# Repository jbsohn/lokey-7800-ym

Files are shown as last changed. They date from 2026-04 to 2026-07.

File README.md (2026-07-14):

# Lokey 7800 YM

> **Status:** v0.2 PCBs have been sent to the manufacturer — prototype boards are pending, and we're working on hardware validation.

## Project Overview

The Atari 7800 community's favorite audio upgrades have a supply problem: POKEY clones run **~$10-$40 each — when they're in stock** — and the YM2151 has been out of production for decades, commanding collector prices used. The **Lokey 7800 YM** takes a different route: the **YM2149 PSG** — the Atari ST's sound chip — is still manufactured today as the **KC89C72** clone for **about $2**. One in-production chip brings three-channel sound to the 7800, and with it a direct bridge to four decades of Atari ST music and a tracker ecosystem that is still alive and composing. Original YM2149 chips are also plentiful as used or New-Old-Stock (NOS) parts.

### What's in a Name?

The **Lokey** name is a triple-layered nod to the project's roots:

- **POKEY**: A respectful "cousin" to Atari’s legendary sound chip.
- **Low-Key**: Reflecting our philosophy of a minimalist, stealthy, and cost-effective design.
- **Loki**: Inspired by the Norse god of mischief—bringing a bit of technical "trickery" to the Atari 7800 bus.

The project views the **Atari ST** as a potential **Creation System**.
With established trackers (like Protracker ST or Maxymiser), it offers a path for audio production. Modern cross-platform tools like [**Furnace Tracker**](https://tildearrow.org/furnace) and [**Arkos Tracker**](https://www.julien-nevo.com/arkostracker/) (which is dedicated specifically to the AY/YM architecture) can also export VGM data for use with our tools on the 7800.

The **Atari 7800** acts as the **Consumer** of these assets. By bridging the hardware gap, we hope to allow the 7800 to play music from the ST era or new compositions from modern trackers.

### Design Goals

- **In-Production Parts Only**: No POKEY or YM2151 unobtainium, and no expensive FPGAs. Every part on the BOM should be sourceable new today (e.g. the KC89C72 YM2149 clone).
- **No SMD**: Hand-solderable through-hole components only, so hobbyists without a hot air rework station can build and repair boards.
- **Low Cost**: Keep the total build cost minimal.
- **Time-Period Accurate**: Stay faithful to what would have been technically feasible/authentic to the Atari 7800/ST era, rather than leaning on modern shortcuts.

### Hardware & Development Status

- **Working Prototype**: We have a hand-built cartridge prototype that has been verified to work.
- **PCB Effort**: We are working on a PCB design using a code-to-PCB workflow (**tscircuit**).
- **Reproducible Hardware Builds**: GitHub Actions rebuilds the PLD logic and both PCBs from source on every push. You can also build locally using the preconfigured **Docker Dev Container** (currently supported for building and routing PCBs).
- **Conversion Tools**: The project includes experimental tools to convert music files. The current C# implementation was a temporary hack to parse ST captures; this will be rewritten in C++ and optimized to support simultaneous music and sound effects playback.
- **SDK Progress**: We are working toward a set of tools and drivers to help others add YM music to their 7800 projects.
- **Custom Emulation**: For testing without hardware, we use forks of **a7800** and **js7800** that implement this specific memory mapping. _If this project gains momentum, we hope these changes might eventually be useful to the official upstream projects._

## Status: STABLE ALPHA

We have achieved playback on physical Atari 7800 consoles using a bitmask-compressed register engine. The current implementation is designed to be efficient, leaving significant CPU time for other tasks.

## See it in Action

### Hardware Prototype

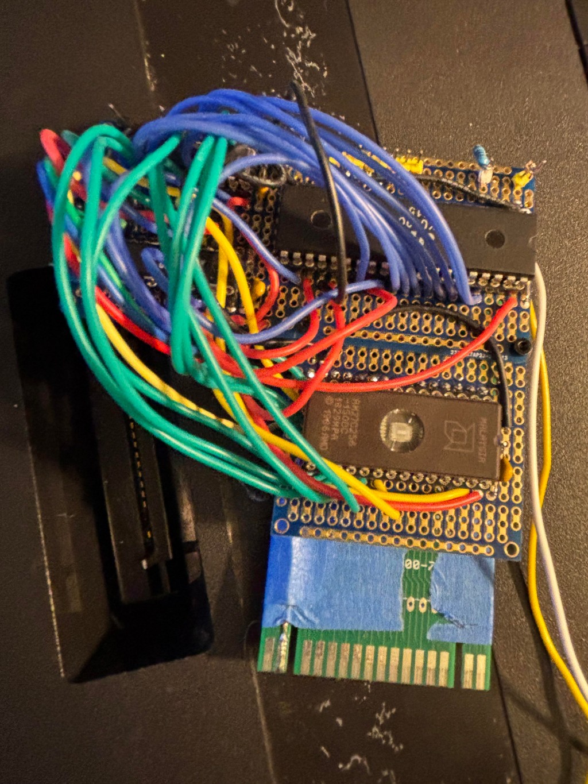
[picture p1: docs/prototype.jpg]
Atari 7800 YM2149 Cartridge Prototype


### Web Emulator (Instant Play)

Test the bridge right now in your browser using our custom **js7800** fork.
👉 **[Play the YM2149 Demos in your Browser](https://jbsohn.github.io/js7800-ym-player/)**

### Real Hardware (ANCOOL1 Stress Test)

This video shows a physical Atari 7800 playing a full 92-second capture of the "ANCOOL1" track, filling 96% of a single 32KB ROM bank to prove bus stability and engine efficiency.

ANCOOL1 Stress Test on Atari 7800 Hardware (https://www.youtube.com/shorts/LWzkfaaal2E)

## Documentation

- **[Development Guide](CLAUDE.md)** - Technical standards and build process for contributors and AI assistants.
- **[AI Development Agents](AGENTS.md)** - Specialized instructions for AI-assisted development and automation.
- **[SDK Samples & Building](docs/Samples.md)** - Compile ROMs and set up the environment.

- **[File Extension Reference](docs/FileExtensions.md)** - Guide to `.ymb`, `.ymi`, `.rom`, and `.a78` files.
- **[Hardware & Wiring](docs/Hardware.md)** - Shared memory mapping and connector/chip pinouts.
  - **[28-Pin Board](docs/Hardware-28pin.md)** - Single-YM2149, jumper-configured ROM board.
  - **[32-Pin Board](docs/Hardware-32pin.md)** - Bank-switched ROM board (fixed 32KB code + 16KB YM-IOA banked data window, 128KB-256KB) (Experimental Pre-Alpha v0.2 - Untested).

- **[PCB Design (tscircuit)](docs/PCB.md)** - Code-to-PCB workflow.

- **[Emulator Support](docs/Emulation.md)** - Using `a7800` and `js7800` for development.

- **[Toolchain & Diagnostics](docs/Tools.md)** - Register conversion (`YmToYmb`, `VgmToYmb`), audio verification (`YmbToWav`), and hardware signal verification.
- **[YMB Format](docs/YmbFormat.md)** - Technical specification of the music binary format.
- **[Musical Credits](docs/Musicians.md)** - Honoring the original composers.
- **[TODO](docs/TODO.md)** - Known issues and improvements.
- **[Future Ideas](docs/FutureIdeas.md)** - Roadmap for hardware/software expansions.

---

## Technical Highlights

- **Hardware**: Uses **YM2149 PSG** mapped to `$0800`/`$0801` (Pokey800-compatible).
- **Compression**: Multi-stage **Pattern-Based Delta Masking** for maximum ROM efficiency.
- **Timing**: Automatic **Pitch Scaling** (1.79MHz vs 2.0MHz) ensures tracks stay in tune.
- **Diagnostics**: Built-in **Software Triad** visualizer for bare-metal debugging.

## Acknowledgements & Credits

- **Karri Kaksonen (karrika)**: For the excellent [Otaku-flash](https://github.com/karrika/Otaku-flash) project. We have integrated the **Stable Alpha** Atari 7800 cartridge footprints, symbols, and professional design rules from this MIT-licensed repository.
- **Simon Frankau ([galette](https://github.com/simon-frankau/galette))**: For the open-source **galette** logic assembler. It provides a modern, cross-platform toolchain for compiling ATF16V8B/ATF22V10 logic, saving us from the legacy Windows tools.
- **Dan Boris (AtariHQ)**: For the indispensable [7800 Cartridge Technical Specifications](https://atarihq.com/danb/7800cart/a7800cart.shtml) and reference diagrams that made this hardware mapping possible.
- **Olivier PONCET (aym-js)**: For the excellent, high-fidelity [aym-js](https://github.com/ponceto/aym-js) YM2149/AY-3-8910 emulator core. Its tone/noise/envelope generator model and DAC tables underpin `tools/Core/AymEmulator.cs` (a literal C# port), which powers `YmbToWav`'s audio verification and has since been ported a second time into Go to give the `test7800` emulator fork native YM2149 support. A small, focused piece of GPL-licensed JavaScript that ended up doing a lot of work across this project — thank you!

- **Arnaud Carré (Leonard/OXG)**: For the excellent [StSound](https://github.com/arnaud-carre/StSound) project. The melodic assets used for hardware testing were sourced via this project's research.

- **Eagle & Ecernosoft**: For the insightful ideas and technical tips provided on the forums, including the Pokey800 mapping recommendation and the inspiration for the "Active Shunt" audio stage design.

- **Original Musicians & Composers**: For the timeless tracks used as benchmarks for this project. See **[Musical Credits](docs/Musicians.md)** for a full list of artists.

- **The Atari Community**: We are grateful to the dedicated fans keeping the 16-bit and 8-bit flames alive through archival and homebrew development.

## Contributing

This project is completely open source, and since this is a first-time PCB design, community feedback and contributions are highly welcome! _"Help! I need someone... not just anybody... you know I need someone!"_ as the Beatles said, so any help or review of the schematics, code, or board layout is greatly appreciated.

## AI Assistance

This project was developed with assistance from AI. For the author, AI has been a "force multiplier"—making it possible to tackle long-held "I've always wanted to do this" projects within the limited hours of evenings and weekends. In particular, it really helped with developing the [route_and_patch.py](file:///home/john/Projects/7800-ym2149-lab/pcb/route_and_patch.py) build pipeline.

For reflections on the legacy of the Atari ST and how AI is changing the landscape of hardware and software side-projects, see the author's blog posts:

[John's Music & Tech](https://johnsmusicandtech.com/)

## License

This repository is dual-licensed:

- **MIT License**: Applies to the 6502 target code ([examples/](file:///home/john/Projects/7800-ym2149-lab/examples) and [include/](file:///home/john/Projects/7800-ym2149-lab/include)). You can use, modify, and distribute this code in your homebrew games without any requirement to open-source your game. See [examples/LICENSE](file:///home/john/Projects/7800-ym2149-lab/examples/LICENSE) and [include/LICENSE](file:///home/john/Projects/7800-ym2149-lab/include/LICENSE).
- **GPL-2.0**: Applies to the host tools ([tools/](file:///home/john/Projects/7800-ym2149-lab/tools)), hardware layouts ([pcb/](file:///home/john/Projects/7800-ym2149-lab/pcb)), PLD logic ([pld/](file:///home/john/Projects/7800-ym2149-lab/pld)), and documentation. Modifying and redistributing these requires sharing your changes. Using these tools to build your ROM does not make your game GPL. See [LICENSE](file:///home/john/Projects/7800-ym2149-lab/LICENSE).

### Why the split?
The emulation core ([AymEmulator.cs](file:///home/john/Projects/7800-ym2149-lab/tools/Core/AymEmulator.cs)) is a C# port of Olivier Poncet's GPL-licensed **aym-js**, requiring GPL compatibility. Since the 6502 code shipped on the cartridge does not link or interact with the host emulator code, it remains under the permissive MIT license.

**Disclaimer:** Use at your own risk. The author is not responsible for hardware damage or data loss.

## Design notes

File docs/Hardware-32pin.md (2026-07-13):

# 32-Pin Board — Theory of Operation & Assembly Guide

**Experimental Pre-Alpha (v0.2):** The fixed+banked YM-IOA bank selection design has not been tested on physical hardware yet and is considered experimental pre-alpha. Use at your own risk. 

**Status:** v0.2 has been sent to the manufacturer; a prototype PCB is pending and this design is not yet hardware-verified.

This document covers the **32-pin ROM board** (`pcb/32pin.circuit.tsx`): a single-YM2149, bank-switched EPROM design with a native DIP-32 socket. The memory layout is SuperGame-style: a **fixed 32KB code bank at $8000–$FFFF** and a **switched 16KB data window at $4000–$7FFF**, with the bank number held in the YM2149's IOA port and decoded by the ATF22V10 PLD. For the shared memory map and pinout references common to all board variants, see [Hardware.md](Hardware.md). For the smaller, jumper-configured board, see [Hardware-28pin.md](Hardware-28pin.md).

## BOM Cost Estimation (Per Unit)

| Component | Part | Estimated Cost | Notes |
| :--- | :--- | :--- | :--- |
| **YM2149 / AY-3-8910 Clone** | U_YM | $2.00 | PSG (KC89C72) |
| **ATF22V10 (Logic)** | U_GAL | ~$1.50 | 24-pin PLD: address decode + bank mapping |
| **AT27C010/020/040 (EPROM)** | U_ROM | $2.00 | 128KB / 256KB (512KB part usable, top half only); native DIP-32 socket |
| **74HCT373 (Octal Latch)** | U_LATCH | $0.40 | Data bus isolation |
| **LM358 (Op-Amp)** | U_AMP | $0.10 | Summing amp for audio out |
| **Passives (R/C)** | — | $0.30 | Reset network, audio mixing, decoupling, 4× bank pull-ups |
| **Total (Excl. PCB)** | | **~$6.30** | |

## Logic Compilation (ATF22V10)

Unlike the 28-pin board (ATF16V8B), this board uses an **ATF22V10** (24-pin PLD). It performs both address decoding _and_ ROM bank mapping: the YM2149's IOA0–IOA3 pins feed the PLD, which generates the ROM's upper address lines A14–A17. Every pin of the PLD is used.

This project uses [**galette**](https://github.com/simon-frankau/galette), an open-source logic assembler. To compile into JEDEC files:

```bash
make logic
```

The source is `pld/rom_ym_32pin.pld`. Core equations:

```
/ROMCE  = A15 * RW  +  /A15 * A14 * RW     ; ROM window $4000–$FFFF, reads only
ROMA14  = A15 * A14 +  /A15 * IOA0         ; fixed: console A14; banked: bank bit 0
ROMA15  = A15 + IOA1                       ; fixed region forces the top of the chip
ROMA16  = A15 + IOA2
ROMA17  = A15 + IOA3
```

Because the fixed bank lives at the **top** of the EPROM (all upper address bits high), "force top bank" is a simple OR against A15 — no mux terms needed.

## Hardware Wiring

### 1. ATF22V10 Pinout (`U_GAL`)

| Pin | Signal | Source / Destination |
| :-- | :--- | :--- |
| 1 | PHI2 | 7800 CPU Clock (Cart Pin 32) |
| 2 | A15 | 7800 Address Bus |
| 3 | A14 | 7800 Address Bus |
| 4 | A13 | 7800 Address Bus |
| 5 | A12 | 7800 Address Bus |
| 6 | A11 | 7800 Address Bus |
| 7 | A0 | 7800 Address Bus |
| 8 | R/W | 7800 CPU R/W Line |
| 9 | HALT | 7800 Maria Halt Signal |
| 10  | IOA0 | ← U_YM Pin 21 (bank bit 0) |
| 11  | IOA1 | ← U_YM Pin 20 (bank bit 1) |
| 12  | GND | Ground |
| 13  | IOA2 | ← U_YM Pin 19 (bank bit 2) |
| 14  | IOA3 | ← U_YM Pin 18 (bank bit 3, used as input) |
| 15  | **ROM_A14** | → U_ROM Pin 29 (A14) |
| 16  | **ROM_A15** | → U_ROM Pin 3 (A15) |
| 17  | **ROM_A16** | → U_ROM Pin 2 (A16) |
| 18  | **ROM_A17** | → U_ROM Pin 30 (A17) |
| 19  | **!ROM_CE** | → U_ROM Pin 22 (~CE) |
| 20  | **BC1** | → U_YM Pin 29 |
| 21  | **BDIR** | → U_YM Pin 27 |
| 22  | **PHI2OUT** | Buffered Clock → U_YM Pin 22 |
| 23  | **YM_LE** | Latch Enable → 74HCT373 Pin 11 |
| 24  | VCC | +5V |

### 2. 74HCT373 Octal Latch Connections

| Latch Pin | Signal | Connection |
| :--- | :----- | :--- |
| 1 | ~OE | Ground |
| 2–9 | Q0–Q7  | U_YM DA0–DA7 |
| 3–18 | D0–D7  | 7800 Data Bus D0–D7 |
| 11 | LE | PLD Pin 15 (YM_LE)  |
| 20 | VCC | +5V |
| 10 | GND | Ground |

### 3. AT27C010/020/040 ROM (Native DIP-32 Socket)

The board carries a native 32-pin DIP-32 (600mil) socket compatible with the AT27C010 (128KB), AT27C020 (256KB), and AT27C040 (512KB) EPROM family. All three share the same pinout; only pins 30–31 differ in function across devices. The upper address lines **A14–A17 come from the PLD** (which muxes between console A14 and the YM IOA bank bits); only A0–A13 come directly from the console bus.

#### AT27C010 Pinout

| Pin (Left) | Signal | Pin (Right) | Signal |
| :--- | :--- | :--- | :--- |
| **1** | VPP (tied VCC) | **32** | VCC (+5V) |
| **2** | A16 ← PLD Pin 17 | **31** | A18/PGM (tied VCC) |
| **3** | A15 ← PLD Pin 16 | **30** | A17 ← PLD Pin 18 |
| **4** | A12 | **29** | A14 ← PLD Pin 15 |
| **5** | A7 | **28** | A13 |
| **6** | A6 | **27** | A8 |
| **7** | A5 | **26** | A9 |
| **8** | A4 | **25** | A11 |
| **9** | A3 | **24** | OE (tied GND) |
| **10** | A2 | **23** | A10 |
| **11** | A1 | **22** | ~CE ← PLD Pin 19 |
| **12** | A0 | **21** | D7 |
| **13** | D0 | **20** | D6 |
| **14** | D1 | **19** | D5 |
| **15** | D2 | **18** | D4 |
| **16** | GND | **17** | D3 |

> **Pin 30 (A17):** address input on AT27C020/040; no-connect on AT27C010.
> **Pin 31 (A18/PGM):** on AT27C010/020 this is PGM (program enable, must be high for read) — tied to VCC. On AT27C040 it is A18, so tying it to VCC means the 512KB part exposes only its **top 256KB**; program images into the upper half.

### 4. YM2149 / AY-3-8910 Connections (U_YM)

#### Bus & Control

| YM Pin | Signal  | Connection |
| :----- | :--- | :--- |
| 22 | CLOCK | PHI2OUT (PLD Pin 22) |
| 27 | BDIR | PLD Pin 21 |
| 29 | BC1 | PLD Pin 20 |
| 28 | BC2 | VCC |
| 25 | A8 | VCC |
| 24 | !A9 | GND |
| 23 | !RESET  | RESET_DELAYED (RC network) |
| 30–37  | DA7–DA0 | 74HCT373 Q7–Q0 |

#### IOA Port — Bank Register

The YM's IOA port holds the current bank number. Software writes YM **register 14** (Port A); register 7 must configure IOA as output before use. The four bank lines feed the **PLD** (not the ROM directly), each with a **10kΩ pull-up** (`R_BANK0–3`) to VCC.

| YM Pin | Signal | Function |
| :----- | :--- | :--- |
| 21 | IOA0 | Bank bit 0 → U_GAL Pin 10 |
| 20 | IOA1 | Bank bit 1 → U_GAL Pin 11 |
| 19 | IOA2 | Bank bit 2 → U_GAL Pin 13 |
| 18 | IOA3 | Bank bit 3 → U_GAL Pin 14 |
| 17–14  | IOA4–IOA7 | Unassigned |

### 5. Fixed + Banked Memory Layout

> [!NOTE]
> This bank switching scheme is currently experimental pre-alpha and has not yet been tested on physical hardware.

SuperGame-style split, decoded entirely in the ATF22V10:

| Console address | Contents | ROM location |
| :--- | :--- | :--- |
| $8000–$FFFF | **Fixed 32KB** — player code, header, vectors | Top 32KB of the chip (always mapped, ignores IOA) |
| $4000–$7FFF | **Switched 16KB window** — song/level data | 16KB bank _N_, where _N_ = IOA[3:0] |

Software protocol (unchanged from v0.2):

```
Write YM reg 7  (Mixer/IO):  bit 6 = 1 (IOA = output) — preserve mixer bits 0-5!
Write YM reg 14 (Port A):    bits[3:0] = bank number (16KB units)
```

> **Register 7 discipline:** bit 6 of register 7 shares the register with the tone/noise mixer. Every mixer write in the player must OR in `$40` or the bank register reverts to input mode (floating → pull-ups → top bank). With the fixed code bank this is no longer fatal — it only redirects the **data window** — but it will still corrupt whatever the player is streaming.

Supported configurations (16KB banks; the top two banks are the fixed 32KB region, visible in the data window only as mirrors):

| ROM part | Capacity | Data banks |
| :--- | :--- | :--- |
| AT27C010 | 128KB | 6 × 16KB (banks 0–5; IOA3 ignored) |
| AT27C020 | 256KB | 14 × 16KB (banks 0–13) |
| AT27C040 | 512KB (top half used) | 14 × 16KB (banks 0–13) |

> [!IMPORTANT]
> **Known limitation of this revision:** 14 usable banks (256KB) is a hard limit, not a soft one — to be addressed in a later revision.

**Power-on behaviour:** at reset the YM's IOA port is in input mode (Hi-Z), so the pull-ups select bank 15 and the data window shows a mirror of $C000–$FFFF — harmless. The reset vectors and boot code live in the **fixed** bank, which is always mapped, so **no code or vector duplication across banks is required**. Bank switching only ever moves the $4000–$7FFF data window.

### 6. Hardware Reset Logic (Warm Start Fix)

An RC network on YM **Pin 23 (!RESET)** prevents the warm-start stuck-tone issue caused by a quick power cycle bypassing BIOS delays.

1. **10kΩ pull-up:** VCC → Pin 23 (!RESET)
2. **10µF polarised cap:** (+) to Pin 23 (!RESET), (−) to GND

At power-up the discharged cap holds !RESET low for ~100ms while the +5V rail stabilises, then releases it high.

### 7. LM358 Audio Stage (U_AMP — Inverting Summing Amp)

YM channels A, B, C each pass through a **1kΩ isolation resistor** to a shared **SUM_NODE**.

| Pin | Signal  | Connection |
| :---- | :--- | :--- |
| **1** | OUT1 | Op-amp output → R_FB → SUM_NODE (feedback) |
| **2** | IN1_NEG | SUM_NODE |
| **3** | IN1_POS | GND |
| **4** | GND | Ground Plane |
| **5** | IN2_POS | GND (unused channel stability) |
| **6** | IN2_NEG | OUT2 (unity-gain follower) |
| **7** | OUT2 | IN2_NEG (unity-gain follower) |
| **8** | VCC | +5V |

**Output path:** OUT1 → R_SERIES (1kΩ) → C_AUDIO_OUT (+) (10µF) → C_AUDIO_OUT (−) → **Exaudio (Cart Pin 18)**. The R_PULL (1kΩ) from OUT1 to GND biases the output stage into Class-A operation.

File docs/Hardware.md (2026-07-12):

# Hardware Specification & Wiring

This document contains the technical hardware specifications, memory mapping, and pinout references shared across all board variants of the YM2149 Atari 7800 bridge.

## Board Variants

This project has two board designs, each with its own dedicated hardware doc for PLD/ROM wiring, jumpers, and BOM:

* **[28-Pin Board](Hardware-28pin.md)** (`pcb/28pin.circuit.tsx`) — single YM2149, ATF16V8B PLD, solder-jumper ROM size selection (16/32/64KB).
* **[32-Pin Board](Hardware-32pin.md)** (`pcb/32pin.circuit.tsx`) — single YM2149, ATF22V10 PLD, native DIP-32 socket. Fixed 32KB code bank at $8000–$FFFF plus a switched 16KB data window at $4000–$7FFF, bank-selected via the YM IOA port through the PLD (128KB–256KB usable).

Everything below this section — the memory map and connector/chip pinout references — applies to both boards.

## Memory Mapping

The YM2149 is mapped to two specific addresses:

| Address | Function |
| :--- | :--- |
| **$0800** | YM2149 Address Register (select internal register) |
| **$0801** | YM2149 Data Register (write value to selected register) |

This mapping follows the **"YM $800" / Pokey800-compatible** decoding scheme: the PLD decodes a single address bit (`A11`, with `A15-A12` all low) rather than mirroring the chip across a wide window. This frees the entire `$4000-$7FFF` cartridge ROM window for actual game data instead of write-only sound registers, at the cost of dropping compatibility with the older "classic POKEY@$4000" mapping used by games like **Ballblazer** and **Commando**.

### Write-Only Mirroring

The current logic implementation is gated by the `!RW` (Read/Write) line. This means the YM2149 is a "write-only" device at $0800. This allows other devices (like ROM or RAM) to reside at the same memory addresses for **read** operations without bus contention.

---

## Hardware Pinout Reference

### 7800 Cartridge Edge (32-Pin)

From [AtariHQ](https://atarihq.com/danb/7800cart/a7800cart.shtml):

| Pin (1–16) | Signal | Pin (32–17) | Signal |
| :--- | :--- | :--- | :--- |
| **1** | Read/Write (low=Write) | **32** | Phase 2 Clock |
| **2** | Halt | **31** | IRQ |
| **3** | D3 | **30** | Ground |
| **4** | D4 | **29** | D2 |
| **5** | D5 | **28** | D1 |
| **6** | D6 | **27** | D0 |
| **7** | D7 | **26** | A0 |
| **8** | A12 | **25** | A1 |
| **9** | A10 | **24** | A2 |
| **10** | A11 | **23** | A3 |
| **11** | A9 | **22** | A4 |
| **12** | A8 | **21** | A5 |
| **13** | +5V VDC | **20** | A6 |
| **14** | Ground | **19** | A7 |
| **15** | A13 | **18** | External Audio Input |
| **16** | A14 | **17** | A15 |

### AY-3-8910 / YM2149 PSG (40-Pin)

| Pin (Left) | Signal | Pin (Right) | Signal |
| :--- | :--- | :--- | :--- |
| **1** | VSS (Ground) | **40** | VCC (+5V) |
| **2** | N.C. | **39** | TEST 1 |
| **3** | Analog Channel B | **38** | Analog Channel C |
| **4** | Analog Channel A | **37** | DA0 |
| **5** | N.C. | **36** | DA1 |
| **6** | IOB7 | **35** | DA2 |
| **7** | IOB6 | **34** | DA3 |
| **8** | IOB5 | **33** | DA4 |
| **9** | IOB4 | **32** | DA5 |
| **10** | IOB3 | **31** | DA6 |
| **11** | IOB2 | **30** | DA7 |
| **12** | IOB1 | **29** | BC1 |
| **13** | IOB0 | **28** | BC2 (Tie High) |
| **14** | IOA7 | **27** | BDIR |
| **15** | IOA6 | **26** | N.C. |
| **16** | IOA5 | **25** | A8 (Tie High) |
| **17** | IOA4 | **24** | !A9 (Tie Low) |
| **18** | IOA3 | **23** | !RESET |
| **19** | IOA2 | **22** | CLOCK |
| **20** | IOA1 | **21** | IOA0 |

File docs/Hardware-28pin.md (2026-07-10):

# 28-Pin Board — Theory of Operation & Assembly Guide

This document covers the **28-pin ROM board** (`pcb/28pin.circuit.tsx`, formerly "Rev 1"): a single-YM2149, jumper-configurable-ROM-size cartridge. For the shared memory map and pinout references common to all board variants, see [Hardware.md](Hardware.md). For the larger dual-YM/bank-switching board, see [Hardware-32pin.md](Hardware-32pin.md).

## BOM Cost Estimation (Per Unit)

The 28-pin board is designed for high performance at a hobbyist-friendly price point.

| Component | Estimated Cost | Notes |
| :--- | :--- | :--- |
| **YM2149 / AY-3-8910 Clone** | $2.00 | Targeted price for bulk/clones |
| **ATF16V8B (PLD)** | $0.85 | Modern replacement for legacy GAL16V8 |
| **27C256 (32KB EPROM)** | $1.50 | Standard game ROM (16KB/64KB parts also supported, see jumper table below) |
| **74HCT373 (Octal Latch)** | $0.40 | Address latching |
| **LM358 (Op-Amp)** | $0.10 | Active audio amplification |
| **Passives (R/C)** | $0.15 | Reset circuit and audio stage |
| **Total (Excl. PCB)** | **~$5.00** | |

## Logic Compilation (ATF16V8B)

The cartridge uses a programmable logic device (typically an **ATF16V8B** or legacy **GAL16V8**) to handle the address decoding and bus control logic.

This project uses [**galette**](https://github.com/simon-frankau/galette), an open-source logic assembler, for a modern, cross-platform toolchain.

To compile the logic into JEDEC files (for use with a device programmer):
```bash
make logic
```

---

## 1. System Architecture

The 28-pin board bridges the Atari 7800 console's expansion bus with a YM2149 Sound Generator (PSG) and a game EPROM (up to 64KB, jumper-selectable).

```mermaid
graph TD
    subgraph Atari 7800 Console
        Bus[Address & Data Bus]
        Phi2[PHI2 Clock]
        Halt[HALT Pin]
        RW[R/W Pin]
        Exaudio[Exaudio Input Pin 18]
    end

    subgraph 28-Pin Cartridge
        GAL[ATF16V8B PLD]
        Latch[74HCT373 Latch]
        YM[YM2149 PSG]
        ROM[27C256/27C512-family ROM]
        Mixer[LM358 Audio Stage]
        JP1[JP1 Jumper]
        JP2[JP2 Jumper]
    end

    Bus -->|A15-A11, A0, R/W, PHI2, HALT| GAL
    Bus -->|D0-D7| Latch
    Bus -->|D0-D7| ROM
    Bus -->|A0-A13| ROM

    GAL -->|ROM_CE| ROM
    GAL -->|YM_LE| Latch
    GAL -->|BDIR, BC1, PHI2OUT| YM

    Latch -->|DA0-DA7| YM
    JP1 -->|Pin 1 VPP/A15| ROM
    JP2 -->|Pin 27 A14| ROM

    YM -->|Analog A, B, C| Mixer
    Mixer -->|AC Out| Exaudio
```

---

## 2. Address Decoding & Memory Map

The PLD (`U_GAL` — ATF16V8B) acts as the address decoder (see [Hardware.md](Hardware.md#memory-mapping) for the full $0800/$0801 register mapping shared across boards):

* **ROM reads ($4000–$FFFF)**:
  * When `RW = 1` (read) and (`A15 = 1` or `A14 = 1`), the PLD asserts `/ROM_CE` (Pin 19) `LOW`, enabling the EPROM (`U_ROM`).
  * The ROM drives the data bus (`D0–D7`) to return game instructions. This covers both the $8000–$FFFF (32KB, `A15=1`) and $4000–$7FFF (16KB, `A14=1`) windows — see the jumper table in [§7](#7-solder-jumper-configurations-rom-size) for how much of this is actually usable per ROM size.
* **Sound Card Register Space ($0800–$0801, writes only)**:
  * The PLD asserts YM2149 control signals when `A15 = A14 = A13 = A12 = 0` and `A11 = 1` during write cycles (`R/W = 0`). Since `RW = 0` here, `/ROM_CE` is not asserted, so there's no bus contention between the write-only YM2149 and the ROM's read path. Unlike the old $4000-mirrored scheme, this doesn't overlap the ROM window at all, so the full $4000–$FFFF range is available for actual game data.

### ATF16V8B Pinout (`U_GAL`)

Logic source: `pld/rom_ym_28pin.pld`.

| Pin | Signal | Source / Destination |
| :--- | :--- | :--- |
| 1 | CLK | Unused |
| 2 | A15 | 7800 Address Bus |
| 3 | A14 | 7800 Address Bus |
| 4 | A0 | 7800 Address Bus |
| 5 | HALT | 7800 Maria Halt Signal |
| 6 | R/W | 7800 CPU R/W Line |
| 7 | PHI2 | 7800 CPU Clock (Cart Pin 32) |
| 8 | A13 | 7800 Address Bus |
| 9 | A12 | 7800 Address Bus |
| 11 | A11 | 7800 Address Bus |
| 15 | **YM_LE** | Latch Enable → 74HCT373 Pin 11 |
| 16 | **PHI2OUT** | Buffered Clock → U_YM Pin 22 |
| 17 | **BC1** | → U_YM Pin 29 |
| 18 | **BDIR** | → U_YM Pin 27 |
| 19 | **!ROM_CE** | → U_ROM Pin 22/20 (~CE, ROM-size dependent) |
| 20 | VCC | +5V |

---

## 3. Data & Address Multiplexing (74HCT373)

The YM2149 uses a multiplexed address/data bus (`DA0–DA7`), while the Atari 7800 separates them.

* The **74HCT373 Octal Latch (`U_LATCH`)** bridges this gap:
  * When the CPU writes to the sound registers, the PLD asserts `YM_LE` (Latch Enable) `HIGH`.
  * This stores the current data bus value (`D0–D7`) in the latch.
  * The latch outputs (`Q0–Q7`) drive the YM2149's multiplexed pins (`DA0–DA7`), holding the address or data stable for the PSG.

| Latch Pin | Signal | Connection |
| :--- | :--- | :--- |
| 1 | ~OE | Ground |
| 2–9 | Q0–Q7 | U_YM DA0–DA7 |
| 3–18 | D0–D7 | 7800 Data Bus D0–D7 |
| 11 | LE | PLD Pin 15 (`YM_LE`) |
| 20 | VCC | +5V |
| 10 | GND | Ground |

---

## 4. YM2149 / AY-3-8910 Connections (U_YM)

| YM Pin | Signal | Connection |
| :--- | :--- | :--- |
| 22 | CLOCK | PHI2OUT (PLD Pin 16) |
| 27 | BDIR | PLD Pin 18 |
| 29 | BC1 | PLD Pin 17 |
| 28 | BC2 | VCC |
| 25 | A8 | VCC |
| 24 | !A9 | GND |
| 23 | !RESET | RESET_DELAYED (RC network, see [§5](#5-hardware-reset--warm-start-fix)) |
| 30–37 | DA7–DA0 | 74HCT373 Q7–Q0 |

---

## 5. Hardware Reset & Warm Start Fix

A common issue with retro PSG cartridges is a high-frequency stuck hum on system reset or quick power-cycle ("Warm Start"), caused by a quick power cycle bypassing the console's default internal BIOS delays and leaving the YM2149 registers holding garbage data. The **RC Reset Delay network (`R_RESET` / `C_RESET`)** on YM **Pin 23 (!RESET)** solves this.

### Connection & Wiring Guide

The two components meet at a single node connected directly to Pin 23 (!RESET) of the YM2149:

1. **Pull-up resistor (10kΩ):** VCC → Pin 23 (!RESET).
2. **Capacitor (10µF, polarized):** positive (+) terminal → Pin 23 (!RESET), negative (−) terminal → GND.

> **Note:** No manual reset switch is fitted on the PCB. The RC network provides automatic power-on reset only. For a manual override on a breadboard build, wire a normally-open switch in parallel with the capacitor (one contact to `!RESET`, the other to GND) — not required for normal cartridge operation.

### Theory of Operation

At power-up, the discharged capacitor acts as a momentary short to ground, holding `!RESET` low while the +5V rail stabilizes. The capacitor charges through the 10kΩ resistor over roughly 100ms, then releases `!RESET` high and allows the PSG to begin normal operation. This delay ensures the console BIOS has had time to silence the audio channels before the YM2149 comes out of reset, preventing the warm-start stuck-tone issue.

---

## 6. Audio Stage (LM358 — Active-Passive Hybrid Shunt Mixer)

The audio stage uses an LM358 op-amp (`U_AMP`) in a parallel **Active-Passive Hybrid Shunt** configuration. This design uses the op-amp's feedback loop and single-supply saturation limits to act as a passive load that prevents console audio clipping, while incorporating an AC shunt network to smooth out high-frequency square-wave edges.

| Pin | Signal | Connection |
| :--- | :--- | :--- |
| **1** | OUT1 | Op-amp output (feedback loop to Pin 2) |
| **2** | IN1_NEG | Summing node (connected directly to audio line) |
| **3** | IN1_POS | GND |
| **4** | GND | Ground Plane |
| **5** | IN2_POS | GND (unused channel stability) |
| **6** | IN2_NEG | OUT2 (Pin 7, unused channel stability) |
| **7** | OUT2 | IN2_NEG (Pin 6, unused channel stability) |
| **8** | VCC | +5V |

> **Note:** The unused second channel (Pins 5–7) is configured as a unity-gain buffer tied to ground to prevent oscillation and thermal instability.

> **Musician's Note on Op-Amps:** While this circuit is pin-compatible with higher-end op-amps like the **TL072**, real-world testing on the Atari 7800 showed that the humble **LM358** actually produced a more desirable "retro" tone. The LM358's performance on the single 5V rail adds a slight warmth and grit that perfectly complements the YM2149 PSG. That said, any pin-compatible op-amp can be used here.

**Audio Path Details:**

* **Summing Node**: YM2149 Channels A, B, and C each go through a **1kΩ isolation resistor** to a single summing node, which connects directly to Pin 2 of the op-amp.
* **Feedback Loop**: A **1kΩ resistor** connects the summing node (Pin 2) to the op-amp output (Pin 1). Since Pin 3 is grounded, the op-amp output sits at `0V`, making this resistor behave as a passive `1kΩ` load to ground that prevents console clipping.
* **Class-A Bias Pull-Down**: A **1kΩ resistor** connects from Pin 1 (OUT1) to ground (Pin 4) to bias the LM358's output stage into Class-A operation, eliminating crossover distortion.
* **AC Output Coupling Network**: A **1kΩ resistor** in series with a **10µF capacitor** connects Pin 1 (OUT1 / `0V`) to the Atari 7800's **Pin 18 (Exaudio)** input. The resistor connects to the capacitor's positive (+) terminal; the negative (−) terminal connects directly to the console's Exaudio line, blocking DC offset and smoothing square-wave transients.

---

## 7. Solder Jumper Configurations (ROM Size)

Before powering on the cartridge, bridge solder jumpers `JP1` and `JP2` to configure your ROM size:

| Jumper | Left pad | Right pad | Purpose |
| :--- | :--- | :--- | :--- |
| **JP1** | VCC | A15 | Pin 1 (VPP/A15): tie high for 16K/32K, or route A15 for 64K |
| **JP2** | VCC | A14 | Pin 27 (A14): tie high for 16K, or route A14 for 32K/64K |

| ROM size | JP1 (Pin 1, VPP/A15) | JP2 (Pin 27, A14) | Accessible |
| :--- | :--- | :--- | :--- |
| **16 KB (27C128)** | Bridge Left (VCC) | Bridge Left (VCC) | 16KB, mirrored across the decoded range |
| **32 KB (27C256)** | Bridge Left (VCC) | Bridge Right (A14) | 32KB |
| **64 KB (27C512)** | Bridge Right (A15) | Bridge Right (A14) | 48KB, **not mirrored** — see below |

> **Why 48KB, not 32KB, for the 64KB part:** `gal/rom_ym_28pin.pld`'s `/ROM_CE` equation asserts on *any* read (`RW=1`) where `A15=1` OR `A14=1` — not just `A15=1`. With JP1/JP2 both bridged right, the 7800's A15/A14 lines drive the ROM's own A15/A14 pins directly, so $8000–$FFFF (32KB, `A15=1`) and $4000–$7FFF (16KB, `A14=1`) each address a distinct region of the 64KB chip. That's 48KB of genuinely unique, addressable ROM content — not a mirrored 32KB.

> **Note:** This board has no address-line bank switching via software — ROM size selection is fixed at assembly time via the two solder jumpers. For software-controlled ROM bank switching (up to 512KB+) and a second cascaded YM2149, see the [32-pin board](Hardware-32pin.md).

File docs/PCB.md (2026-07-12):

# PCB Design & Automated Routing Pipeline

> [!WARNING]
> **Work in Progress**: The PCB design is in an experimental prototype phase and is **not production-ready**. The physical board has **not yet been ordered or tested** for fabrication.

This document explains the architecture of the Atari 7800 YM2149 sound card cartridge PCB, how the automated compilation and routing pipeline works, and the design decisions made to work around current `tscircuit` limitations.

> [!NOTE]
> **Why we use a custom post-routing pipeline:**
> This project uses **tscircuit** to code-define all component placements, schematic connections, and the initial unrouted PCB footprints. We only use KiCad as a final post-processing stage to complete trace routing, apply low-level DRC patches, and generate manufacturing files. 
> 
> Because the native `tscircuit` layout engine and design-rule configurations are currently optimized for simpler boards, our build runner (`pcb/route_and_patch.py`) programmatically exports the unrouted design, patches the board parameters using the KiCad Python API, and offloads the double-sided routing to `Freerouting`.
> 
> **Important**: KiCad is used purely as a post-processing tool to push the `tscircuit` design over the finish line. This project is **not** intended to be developed or edited manually in KiCad; any manual modifications will be overwritten upon the next build.
> 
> As `tscircuit` matures, the ultimate goal is to eliminate these external scripts and perform all design rule configurations and routing natively within the framework.

---

## PCB Overview
Each board is a **2-layer cartridge PCB** currently in the **experimental prototype phase (not production-ready)**. The project is still in its early stages, and neither board has been ordered for physical fabrication. While they interface the Atari 7800's expansion port to a YM2149 sound chip, address decoding logic, and audio pre-amplifier, mechanical verification and adjustments to fit standard cartridge shells remain a work-in-progress.

There are two board designs, defined as separate tscircuit entry files under `pcb/`:

* **`28pin.circuit.tsx`** — single YM2149, ATF16V8B PLD, solder-jumper ROM size selection. Full wiring/BOM: [Hardware-28pin.md](Hardware-28pin.md).
* **`32pin.circuit.tsx`** — single YM2149, ATF16V8B PLD, native DIP-32 socket with software bank switching via the YM IOA port. Full wiring/BOM: [Hardware-32pin.md](Hardware-32pin.md).

This document covers only the shared code-to-PCB pipeline; see the two hardware docs above for chip pinouts, jumper/bank-switching configuration, and per-board BOM.

### Board Previews:

> [!NOTE]
> These previews link to the [latest GitHub Release](https://github.com/jbsohn/lokey-7800-ym/releases/latest) build artifacts rather than files checked into this repo, so they always reflect the most recently tagged `v*` release (not necessarily the current `main` branch).

#### 28-Pin Board Previews

| Front View (Top Copper) | Back View (Bottom Copper) | 3D Render (Isometric) |
| :---: | :---: | :---: |
| 28-pin Front | 28-pin Back | 28-pin 3D |

#### 32-Pin Board Previews

| Front View (Top Copper) | Back View (Bottom Copper) | 3D Render (Isometric) |
| :---: | :---: | :---: |
| 32-pin Front | 32-pin Back | 32-pin 3D |

> [!NOTE]
> The 3D renders show bare copper/silkscreen/drill geometry without component bodies — the `tscircuit`-generated footprints don't currently have 3D models (STEP/WRL) assigned, so chips, connectors, and passives don't appear as solid parts yet.

---

## Compilation & Routing Pipeline

Because we maintain a code-first design, the single source of truth for each board is its own entry file — `pcb/28pin.circuit.tsx` or `pcb/32pin.circuit.tsx`. Generating the final routed KiCad project and manufacturing-ready Gerber/Drill files is automated via `make pcb-28pin` or `make pcb-32pin` (`make pcb` is an alias for `make pcb-32pin`).

To quickly regenerate the SVG visual board previews for documentation (using the currently compiled board design), you can run the standalone command:
```bash
make previews
```

To keep the pipeline robust, we interface directly with the **official KiCad Python API (`pcbnew`) and native `kicad-cli` commands** wherever possible rather than relying on custom text parsers.

The build runner (`pcb/route_and_patch.py <entry-file>.circuit.tsx`) executes the following sequential steps:

```mermaid
graph TD
    A[React Code *.circuit.tsx] -->|npx tsci export| B[Unrouted KiCad PCB]
    B -->|pcb/route_and_patch.py| C[Patched KiCad PCB & Rules]
    C -->|kicad-cli / python pcbnew| D[Specctra DSN Export]
    D -->|Boundary & Clearance Patch| E[Freerouting Session]
    E -->|Import SES| F[Routed KiCad PCB]
    F -->|kicad-cli DRC & Refill| G[Gerbers & Drill Files]
```

### Pipeline Steps:
1. **Export**: Compiles the React TSX file into an unrouted KiCad board (`.kicad_pcb`). We set `routingDisabled={true}` on the `<board>` in React to bypass the native layout engine, offloading the double-sided routing workload to the DSN/SES loop.
2. **Patching Design Settings (`route_and_patch.py`)**:
   * **Stubs**: Cleans up dummy `tscircuit:Unknown` footprint stubs.
   * **Silkscreen**: Standardizes reference designator text dimensions (height/width $\ge 0.8\text{mm}$, thickness $\ge 0.1\text{mm}$) to satisfy manufacturing silkscreen rules.
   * **DRC Severity**: Disables cosmetic warnings (e.g., missing footprints from libraries, text size out of range) in the project settings (`.kicad_pro`).
   * **Zone Filling**: Sets GND zones to always remove isolated copper islands (`SetIslandRemovalMode(0)`) and decreases zone `min_thickness` to `0.15mm`. This is a workaround that allows GND copper pours to flow continuously through the tight right-shoulder board notches, maintaining ground plane integrity.
   * **Custom Rules (`.kicad_dru`)**: Writes custom KiCad design rules to waive edge clearances specifically for the card-edge connector `J1` pads, allowing tight VCC/GND/signals to escape through the narrow connector notches.
3. **DSN Export**: Exports the board into Specctra DSN format using the `pcbnew` Python API.
4. **DSN Patching**:
   * Modifies clearance rules inside the DSN file so Freerouting handles the SMD edge pads correctly.
   * Pads the bottom DSN boundary coordinate to `-140.2mm` (instead of `-140.0mm`). This provides the minimum `0.2mm` clearance Freerouting needs to route the edge pins flush to the physical board edge without failing.
5. **Freerouting**: Launches the Freerouting CLI to automatically route all signals.
6. **Import**: Imports the generated Specctra SES route session back into the `.kicad_pcb` board.
7. **DRC & Zone Refill**: Refills all copper zones and executes `kicad-cli` Design Rule Checking.
8. **Export Gerbers**: Outputs production-ready plot files to `pcb/build/gerbers/`.

---

## Requirements & Build Instructions

> [!NOTE]
> Fabrication-ready Gerber files are **not** stored in this repository. A GitHub Actions workflow (`.github/workflows/release.yml`) automatically builds both boards and attaches Gerber archives (`gerbers-28pin.zip`, `gerbers-32pin.zip`) to each [GitHub Release](https://github.com/jbsohn/lokey-7800-ym/releases) — grab those if you just want to order the PCB. You only need to set up the dependencies below if you plan to modify the PCB code or rebuild the layout yourself.

### Requirements

#### Docker Dev Container (Optional)

An optional, preconfigured Dev Container is provided in the `.devcontainer/` folder. Opening the project in this container sets up a gold-standard environment that mirrors the GitHub Actions runner, pre-installing Node.js, Bun, Java, Cargo, KiCad 9.0, freerouting, `dasm`, and the `.NET SDK`.

> [!IMPORTANT]
> At this stage of the project, the Dev Container is only fully configured and supported for **building and routing the PCB, schematics, and PLD logic**.

#### Manual Setup Requirements

1. **Node.js (v18+) & npm/bun**: Required to run the `tscircuit` React-to-PCB compiler.
2. **KiCad (v7.0 or v8.0+)**:
   - `kicad-cli` must be available in your system `PATH`.
   - The Python scripting environment (`pcbnew`) must be installed. On macOS, this is typically bundled inside the KiCad application. On Linux, install python3-kicad.
3. **Freerouting**:
   - Freerouting is a Java application, so a **Java Runtime Environment (JRE 21+)** must be installed and on `PATH`.
   - The documented way to run it is `java -jar freerouting-X.Y.Z.jar` (see the [official CLI docs](https://github.com/freerouting/freerouting/blob/master/docs/command_line_arguments.md)). Download a release jar and point `FREEROUTING_JAR` at it — this is the preferred method on **every platform, including macOS**.
   - Alternatively, if you already have a `freerouting` executable/wrapper installed and on `PATH` (e.g. a distro package), it'll be used as a fallback, or you can point `FREEROUTING_BIN` at it directly.

### Build Instructions

1. **Install Node dependencies**:
   Navigate to the `pcb/` directory and install the packages:
   ```bash
   cd pcb
   npm install
   ```

2. **Compile and Route the PCB**:
   From the repository root directory, run one of:
   ```bash
   make pcb-28pin
   make pcb-32pin   # same as `make pcb`
   ```
   Each target automates the entire pipeline for that board:
   - Runs `route_and_patch.py` to compile the React code, apply design tweaks, auto-route the traces using Freerouting, and run the final Design Rule Check (DRC).
   - Populates the production Gerber/Drill files in `pcb/build/gerbers/` and archives them as `pcb/build/gerbers.zip`.

   Run `make schematic-28pin` / `make schematic-32pin` to generate that board's schematic diagram, and `make previews-28pin` / `make previews-32pin` to export that board's front/back PNGs plus an isometric 3D render to `build/` (`pcb_front_<board>.png` / `pcb_back_<board>.png` / `pcb_3d_<board>.png` — gitignored build output, not checked into the repo). `make previews` is an alias for `make previews-32pin` only.

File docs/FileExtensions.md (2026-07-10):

# Atari 7800 YM2149 Project File Reference

This document describes the various file extensions and build artifacts used in the YM2149 toolchain.

## Asset & Source Files

| Extension | Name | Description |
| :--- | :--- | :--- |
| `.ym` / `.YM` | YM Sample | Original Atari ST / Amstrad CPC music files (YM2149 register dumps). |
| `.vgm` / `.vgz` | VGM Sample | Video Game Music files containing AY-3-8910 command streams. |
| `.asm` | 6502 Assembly | Source code for the music player, logic ROMs, and hardware drivers. |
| `.pld` | CUPL Logic | Source code for the PLD address decoder, compiled with `galette` (see `pld/`; ATF16V8B on the [28-pin board](Hardware-28pin.md), ATF22V10 on the [32-pin board](Hardware-32pin.md)). |

## Intermediate Build Artifacts

| Extension | Name | Description |
| :--- | :--- | :--- |
| **`.ymb`** | **YM Binary** | Custom compressed music data. Uses delta-masking and pattern deduplication. Replaced generic `.bin`. |
| **`.ymi`** | **YM Info** | Sidecar metadata file for DASM. Contains timing constants (`PLAYER_HZ`, `YM_DELAY`) and data offsets. Replaced `.yminc`. |
| `.wav` | Verification Audio | 44.1kHz PCM audio rendered from the `.ymb` data to verify conversion accuracy. |

## Target ROMs & Hardware Files

| Extension | Name | Description |
| :--- | :--- | :--- |
| **`.rom`** | **Hardware ROM** | Raw 32KB binary image. These are **signed** via `7800sign` and are ready to be flashed to physical EPROMs. |
| **`.a78`** | **Emulator ROM** | Includes a standard 128-byte Atari 7800 header. Used for testing in emulators like A7800, B7800, or JS7800. |
| `.jed` | JEDEC Logic | Compiled fuse map for the PLD, generated from `.pld` files via `galette`. |

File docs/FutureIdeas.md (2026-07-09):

# Future Ideas & Experimental Enhancements

This document captures long-term project roadmaps, experimental concepts, and hypothetical enhancements for the Lokey-YM project.

---

## 1. Hardware Supervisors & Co-Processors

### ATtiny85 Startup Supervisor (The "Chime" Module)
Adding a low-cost ATtiny85 microcontroller to act as a hardware supervisor during boot.
*   **Startup Chime**: Plays a signature computation sound or musical jingle immediately at power-on.
*   **Decryption Overlay**: Plays sound while the Atari 7800 BIOS is verifying the cartridge signature (which takes 2-3 seconds), giving the user audio feedback that the system is booting.
*   **Register Crush**: Performs a hardware-level silent reset of all YM2149 registers before the 6502 code begins execution.

### Independent Audio Co-Processor
Expanding the ATtiny supervisor logic to handle simple sound effects (SFX) or "achievement dings" independently of the main 6502 CPU, offloading basic audio tasks from the game loop.

---

## 2. YM2149 I/O Port Expansion

Since the YM2149's parallel I/O ports are unused on the 28-pin board and only partially used for bank-switching on the 32-pin board, they could drive future hardware expansions:

*   **Serial Debugging**: Bit-banging a UART protocol through an I/O pin to send real-time debug telemetry to a PC.
*   **External Flight Recorder**: Connecting to an Arduino or logic analyzer to record 6502 CPU bus transactions.
*   **Custom Controllers**: Interfacing SNES controllers or other non-standard inputs directly to the cartridge.
*   **MIDI/Synthesizer Interface**: Exposing I/O pins for MIDI-In control.
*   **Mass Storage (SPI)**: Interfacing with an SD card reader.
*   **Non-Volatile Save Storage (SPI FRAM/EEPROM)**: Bit-banging an SPI interface (SCK, MOSI, MISO, CS) using 4 I/O pins to read/write persistent save states, high scores, or game progress to an external SPI FRAM or EEPROM chip without needing a battery backup.

---

## 3. Physical Form Factor & Output

### Direct Audio Output Jack
Adding a dedicated 3.5mm Stereo Jack directly to the top of the cartridge.
*   **High Fidelity**: Bypasses the noisy RF/internal audio circuitry of the Atari 7800.
*   **Custom Stereo Mix**: Allows panning the three PSG channels across left/right channels.

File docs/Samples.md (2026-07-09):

# SDK Samples & Building Guide

This guide covers the core sample applications included with the Lokey-YM SDK and provides instructions on how to build them.

## 1. Prerequisites

To build the samples and music tracks, you need the following:

* **Assembler**: Either **DASM** or **Mad Assembler (MADS)**.
* **.NET SDK**: Required for the diagnostic and processing tools. These have been verified on Linux and macOS.

---

## 2. The Core Samples

The samples are located in the `examples/` directory and demonstrate different aspects of YM2149 sound production on the Atari 7800.

### Universal Samples (DASM & MADS)

These use a "Universal Subset" of 6502 assembly compatible with both assemblers.

* **Universal Triad (`triad.asm`)**: A bare-metal diagnostic test that plays a C-Major triad (C3, E3, G3). Shows direct register writes to `$0800`/`$0801`.
* **Universal Player (`player.asm`)**: The core engine for playing compressed `.ymb` files with high-precision fractional timing.

### MADS "Pro" Sample (MADS Only)

These showcase high-level features available exclusively in **Mad Assembler (MADS)**.

* **MADS Pro Triad (`triad_mads.asm`)**: A modernized version of the triad demo using encapsulated procedures (`.PROC`), register-based parameter passing (`.REG`), and ergonomic moves (`MVA`).

---

## 3. Build Instructions

The SDK supports a dual-assembler workflow via the root `Makefile`.

### Build Commands

| Target | Command | Description |
| :--- | :--- | :--- |
| **Emulator (DASM)** | `make a78` | Build the universal samples and music using DASM. |
| **Emulator (MADS)** | `make a78 ASSEMBLER=mads` | Build the universal samples and music using MADS. |
| **Pro Demo** | `make pro` | Build the MADS-exclusive "Pro" triad demo. |
| **Hardware ROMs** | `make rom` | Build and sign raw 32K binary images for EPROMs. |
| **Verification** | `make wav` | Generate `.wav` files for all music tracks. |
| **Cleanup** | `make clean` | Remove all generated build artifacts. |

### Build Results
All commands output to the `build/` directory:
- **`.a78`**: Packed ROM with a 128-byte header for emulators (a7800, js7800).
  > [!NOTE]
  > The `a78gen` tool used for header generation is a **work in progress**. Future updates will provide improved mapping for complex cartridge header types and bank-switching configurations.
- **`.rom`**: Raw 32,768-byte binary image, signed for hardware.

---

## 4. Hardware Deployment

### Signing for Real 7800 Hardware

Atari 7800 cartridges must be signed. While `make rom` handles this automatically, you can sign a raw binary manually:

```bash
7800sign -w build/your_app.rom
7800sign -t build/your_app.rom
```

### ROM Footer Requirements

For the signature to be valid, the ROM must have a specific 8-byte footer starting at `$FFF8`. In the SDK samples, this is handled natively for both assemblers.

For more details on writing compatible code, see the **[Universal Assembly Guidelines](UniversalAssemblyGuidelines.md)**.

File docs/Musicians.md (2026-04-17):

# Musical Credits

This project would not be possible without the incredible compositions of the original musicians. These tracks serve as the benchmark for our YM2149 hardware bridge.

## Atari ST Composers (YM Samples)

The following tracks were sourced from the **StSound** collection and represent the "Golden Age" of Atari ST chipmusic.

| Track | Game / Demo | Composer |
| :--- | :--- | :--- |
| `ANCOOL1.ymb` | An Cool | **Mad Max (Jochen Hippel)** |
| `enchant1.ymb` | Enchanted Lands | **Jochen Hippel** |
| `ND-Loader.ymb` | Nostalgic-O-Demo | **TAO of ACF** |
| `ND-Toxygene.ymb` | Nostalgic-O-Demo | **TAO of ACF** |
| `Scout.ymb` | Scout | **Jochen Hippel** (based on Jeroen Tel) |
| `VirtualEscape1.ymb`| Virtual Escape | **Jedi / Sector One** |
| `VirtualEscape2.ymb`| Virtual Escape | **Furax / Equinox** |

## Modern & Multi-Platform Composers (VGM Samples)

These tracks demonstrate the YM2149 / AY-3-8910 legacy across multiple platforms (ZX Spectrum, CPC, and modern trackers).

| Track | Platform / Tracker | Composer |
| :--- | :--- | :--- |
| `AY-3-8910_Jam.ymb` | VGM / Furnace | **DeMOSic** |
| `Buzz-o-Meter.ymb` | VGM / ZX Spectrum | **Doclands / C.Wild** |

---

## Technical Note on Asset Usage
These musical assets are included for educational and hardware verification purposes. All rights and copyrights remain with the original authors. We appreciate the opportunity to test our project with their compositions.

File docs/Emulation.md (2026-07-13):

# Emulator Support

To iterate rapidly without burning EPROMs, you can use these specialized forks that include full support for the physical YM2149 hardware mapping.

## A78 Header & Emulator Detection

The project uses a **v4 A78 Header** (an extension of the standard 128-byte header) to signal to the emulator that YM2149 hardware is present.

- **Header Version**: `4` (Offset 0)
- **Audio Location**: `$0800` written into Offset 66–67 (`A78Gen`'s `audio` field) — the real YM2149 address register location.
- **Cart Type Flag**: Bit 2 of the Cart Type low byte (Offset 54) is force-set as a redundant "YM2149 present" flag for older emulator support.
- **Mapper** (Offset 64): `0` = Linear (fixed 32KB, no bankswitching). `1` = 32-pin board's YM-IOA bank scheme — fixed 32KB at `$8000-$FFFF` plus a 16KB window at `$4000-$7FFF` bank-selected via the YM2149's IOA port (see [Hardware-32pin.md](Hardware-32pin.md)). `A78Gen` sets this from the `mapper` field in its config JSON; for mapper 1 the input binary must be the full 128KB or 256KB ROM image, not just the fixed bank.

> **Emulator fork compatibility note**: As of the move to the $0800/$0801 "Pokey800" mapping (see [Hardware.md](Hardware.md#memory-mapping)), Offset 66 is `$08` rather than `$40`. The `a7800`/`js7800` forks below historically detected YM2149 presence by checking **bit 6** of Offset 66 (`%01000000`), which only happened to work because $4000's high byte is `0x40`. That bit-6 check no longer matches and needs a corresponding update in those forks — until then, rely on the Cart Type bit 2 flag (Offset 54) for detection, or patch the forks to read the full 16-bit Offset 66–67 value as the actual mapped address instead of a fixed bit flag.

When the `a7800` or `js7800` forks detect YM2149 hardware in a `.a78` file, they automatically enable the YM2149 engine and map it to the **$0800–$0801** range.

## a7800 (Desktop)
A desktop emulator for the 7800, updated here to include support for this YM2149 memory mapping.

- **Repository**: [https://github.com/jbsohn/a7800](https://github.com/jbsohn/a7800)
- **Branch**: `ym2149`
- **Key Enhancements**:
  - **Native Apple Silicon Support**: Runs natively on **macOS M1/M2/M3** CPUs.
  - **Hardware Accuracy**: Implements the physical memory mapping ($0800–$0801) used by this project. *(Needs update for the Pokey800 remap — see compatibility note above.)*
  - **AY/YM Engine**: Full emulation of the YM2149 PSG, synchronized with the 7800 PHI2 clock.

## js7800 (Web-based)

A browser-based emulator that allows for zero-setup testing and sharing.

- **Live Demo**: [**Play the YM2149 Demo in your Browser**](https://jbsohn.github.io/js7800-ym-player/)
- **Repository**: [https://github.com/jbsohn/js7800](https://github.com/jbsohn/js7800)
- **Branch**: `ym2149`
- **Key Enhancements**:
  - **WebAudio Integration**: Bridges the 6502 register writes to the browser's audio engine for real-time playback.
  - **Rapid Iteration**: Open sourceyour `.a78` builds directly into the browser.
  - **32-Pin Bank Switching**: Emulates the Mapper 1 YM-IOA bank scheme (`CARTRIDGE_TYPE_YM_BANKED` in `Cartridge.js`) — the `$4000-$7FFF` window follows the YM2149's IO Port A whenever register 7 has it configured as an output, including the 128KB chip's bank-number aliasing (no A17 pin) and the power-on pull-up float to the fixed-region mirror.

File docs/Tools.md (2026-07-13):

# Toolchain & Diagnostics Guide

This document describes the compilation, conversion, verification, and diagnostic tools used in the Lokey-YM project. All tools require the **.NET SDK**.

> [!IMPORTANT]
> These C# tools are **experimental** and primarily intended for **early testing** of the YM2149 on Atari 7800 cartridges.
> 
> The C# implementation was a temporary hack to quickly parse and verify Atari ST captures. In future development, these tools will be rewritten in C++ and optimized for a driver architecture that supports simultaneous sound effects and music playback.

> [!NOTE]
> The current toolchain and the `.ymb` music format were developed as a proof of concept to quickly get YM music playing on physical cartridges, and are subject to change in future revisions.

---

## 1. Music Conversion & Verification

We provide tools to convert register streams into our custom, compressed `.ymb` music format and verify the output.

### `YmToYmb` (Atari ST Captures)
Converts Atari ST **YM** files (register dumps from legacy ST trackers).
*   **Formats**: YM2, YM3, YM4, YM5, and YM6.
*   **Usage**: 
    ```bash
    dotnet run --project tools/YmToYmb/YmToYmb.csproj -- <input.ym> [options]
    ```

### `VgmToYmb` (Modern Trackers)
Converts **VGM/VGZ** command streams. This is the preferred route for new compositions.
*   **Trackers**: [Furnace Tracker](https://tildearrow.org/furnace) or [Arkos Tracker](https://www.julien-nevo.com/arkostracker/).
*   **Usage**: 
    ```bash
    dotnet run --project tools/VgmToYmb/VgmToYmb.csproj -- <input.vgm> [options]
    ```

### `YmbToWav` (Audio Verification)
Renders `.ymb` music data back into standard `.wav` audio to verify conversion accuracy.
*   **Accuracy**: Aims to reproduce the YM2149's logarithmic volume curve and hardware envelopes.
*   **Usage**: 
    ```bash
    dotnet run --project tools/YmbToWav/YmbToWav.csproj -- build/song.ymb [output.wav]
    ```

---

## 2. Core Music Processing Theory

For the complete technical layout of the generated output, see the **[YMB Format Technical Specification](YmbFormat.md)**.

1.  **Pitch Scaling (The Clock Problem)**: The Atari ST's YM2149 chip is clocked at **2.0 MHz**, while the Atari 7800's PHI2 clock (which drives the YM chip in this project) is **~1.79 MHz** (NTSC). Without scaling, notes would sound flat. The tools multiply frequency and noise registers by a `pitchScale` ratio (~0.895) so music plays in tune.
2.  **Delta Masking**: To avoid writing 14 bytes/frame, a **16-bit bitmask** precedes every frame. If a bit is `1`, the register value follows. If `0`, the register remains unchanged from the previous frame. Silent or repetitive frames shrink from 14 bytes down to just 2 bytes.
3.  **Pattern Deduplication**: The converter slices songs into fixed-size patterns, identifies identical patterns, and stores only unique pattern blocks. It automatically tests multiple pattern sizes to find the best compression ratio.

---

## 3. Hardware Signal Diagnostics

These scripts help validate physical signals coming off the Atari 7800 cartridge edge connector before they reach the ROM or YM2149.

### `tools/Scripts/ValidateCartSignals.cs`
Validates physical signals coming off the edge connector.
*   **Requirements**: `sigrok-cli` and a logic analyzer (e.g., `fx2lafw`).
*   **Target Signals**: Analyzes `PHI2`, `R/W`, `HALT`, and `A15` for stable transitions.

### `tools/Scripts/ValidateLogicSignals.cs` & `tools/Scripts/ValidateLatchEnable.cs`
Advanced timing diagnostics used to detect mid-cycle address bus noise or "shattered" pulses.
*   **Timing Check**: Ensures `YM_LE`, `BDIR`, and `BC1` only trigger when the `PHI2` clock is stable.
*   **BC1 Monitor**: Confirms the logic equations correctly identify register selection (A0=0) vs. data writes.

---

## 4. ROM Packaging Tools

### `tools/A78Gen/Program.cs`
Generates a 128-byte A78 header and packages a raw binary for emulator use.
*   **Status**: **Work in Progress**.
*   **Mapper**: set `"mapper": 1` in the config JSON to package the 32-pin board's YM-IOA bank scheme (see [Emulation.md](Emulation.md#a78-header--emulator-detection)) — the input binary must then be the full 128KB or 256KB ROM image, not just the fixed 32KB bank. `"mapper": 0` (default) keeps the original fixed-32KB-only behavior.
*   **Usage**:
    ```bash
    dotnet run --project tools/A78Gen/A78Gen.csproj -- <input.bin> <config.json> -o <output.a78>
    ```
*   **Planned Improvements**: Mapping for other cartridge header types (SuperGame, Activision, etc.) beyond the fixed-32KB and YM-IOA-banked cases.

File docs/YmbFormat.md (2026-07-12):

# Atari 7800 YM2149 YMB Music Format

> [!WARNING]
> **Work in Progress**: The `.ymb` format was developed as an experimental proof of concept to quickly test YM and VGM register stream playback on physical cartridges. As such, **the format is subject to change**. Future revisions will align with the planned C++ codebase rewrite to support concurrent music and sound effects playback.

This document specifies the custom binary format used to store compressed YM2149 music assets for the Atari 7800. This format is designed for efficiency in a limited ROM, while aiming for low CPU overhead on the 6502.

## 1. Header Structure

The file begins with a 3-byte fixed header:

| Offset | Size | Name | Description |
| :--- | :--- | :--- | :--- |
| 0 | 1 byte | `PatternSize` | Number of frames in each pattern block (e.g., 32, 64). |
| 1 | 1 byte | `NumUnique` | Total number of unique pattern blocks stored (Max 255). |
| 2 | 1 byte | `SeqLen` | Total number of entries in the sequence table (Max 255). |

## 2. Sequence Table

Following the header is the **Sequence Table**. This table defines the playback order of the song.

* **Size**: `SeqLen` bytes.
* **Format**: Each byte is an index (0 to `NumUnique-1`) pointing to a unique pattern.

## 3. Pattern Offset Table

Immediately following the Sequence Table is the **Offset Table**. This table allows the 6502 player to quickly find the start of each unique pattern in ROM.

* **Size**: `NumUnique * 2` bytes.
* **Format**: 16-bit pointers (Little-Endian).
* **Reference**: These offsets are relative to the start of the **Pattern Data** block.

## 4. Pattern Data

The final and largest block is the raw **Pattern Data**.

* **Compression**: Data is stored using **Bitmask Deltas**.
* **Frame Structure**: Each audio frame consists of:
    1. **Mask (2 bytes)**: A 16-bit little-endian value. Bits 0–13 represent YM2149 registers 0–13.
    2. **Payload (Variable)**: Only the register values corresponding to the `1` bits in the mask are stored, in sequential order.

### Example Frame

If only Register 0 (Tone A Low) and Register 8 (Volume A) changed:
* **Mask**: `0x0101` (Binary `%00000001 00000001`)
* **Data**: `[Reg0 Value][Reg8 Value]`
* **Total Size**: 4 bytes (instead of 14).

## 5. Architectural Advantages

### O(1) Seeking

By using fixed-size patterns and an offset table, the 6502 player can instantly calculate the memory address of any part of the song without parsing linear data.

### Zero Arithmetic

The pitch scaling and timing pre-calculations are performed on the PC at build-time. The 7800 simply dumps the raw bytes into the registers, ensuring that even complex trackers (like Furnace) leave 90%+ of the CPU available for game logic.

### Hardware-Correct Envelopes

Register 13 (Envelope Shape) is treated as "volatile" by the converters. Even if the shape value doesn't change, a write is forced if the tracker composition demands a reset, ensuring the characteristic YM "buzz" is preserved.

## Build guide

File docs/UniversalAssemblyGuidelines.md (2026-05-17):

# Universal 6502 Assembly Guidelines (DASM & MADS)

The Lokey-YM SDK supports both **DASM** (the community standard) and **MADS** (for advanced development). To maintain a single source of truth for core logic, we use a "Universal Subset" of 6502 assembly combined with conditional blocks.

Here are the guidelines for writing dual-compatible code.

## 1. The `MADS` Define
The primary mechanism for compatibility is a conditional block based on a `MADS` variable. This variable must be defined on the command line during assembly.

**Compilation Commands:**
*   **DASM:** `dasm source.asm -DMADS=0 -f3 -osource.bin`
*   **MADS:** `mads source.asm -d:MADS=1 -o:source.bin`

## 2. Setup and Includes
Because DASM and MADS have different ways of handling includes (`include` vs `icl`) and memory mapping (`org` vs `blk none`), every universal file should start with a setup block:

```assembly
    .if MADS
      opt h- f+        ; No DOS header, raw binary
      icl "maria.inc"
      icl "ym2149.inc"
      blk none $8000   ; Map to $8000
    .else
      processor 6502
      include "maria.inc"
      include "ym2149.inc"
      org $8000
    .endif
```

## 3. Universal Data Directives
Both assemblers support dot-prefixed directives for raw data. Avoid assembler-specific shortcuts.

*   ❌ **Don't use:** `dc.b`, `dc.w`, `dta b()`, `dta a()`
*   ✅ **Do use:** `.byte`, `.word`

```assembly
note_table_lo:
    .byte <428, <381, <339
note_table_hi:
    .byte >428, >381, >339
```

## 4. Labels and Scopes
DASM requires all labels and equates to start in the **first column**. MADS is more flexible but will accept column-1 labels.

*   ✅ **Always** start your labels and equates in column 1.
*   ❌ **Don't use** `.proc`, `.zpvar`, or `.local` in universal code, as DASM does not support them.

## 5. Local Labels
Both assemblers support local labels, but the syntax differs. To remain universal, avoid the dot-prefix (`.loop`) and use unique names or underscore prefixes if supported by your specific versions.
*   **Recommended**: Use descriptive unique names (e.g., `_wait_vbi`) rather than relying on local-scope markers.

## 6. ROM Padding & Vectors
Atari 7800 ROMs must be exactly 32,768 bytes with vectors at the very end. Use a conditional block to handle the padding difference:

```assembly
    .if MADS
        .align $fff8, $ff
        .byte $ff, $83  ; Footer/Cart Type
        .word reset, reset, reset
    .else
        org $fff8, $ff
        .byte $ff, $83
        .word reset
        .word reset
        .word reset
    .endif
```

## 7. Instruction Set
Stick to the standard 6502 instruction set.

*   ❌ **Don't use:** `mva`, `adw`, `#if`, `#while` (MADS specific macros)
*   ✅ **Do use:** `lda`, `sta`, `cmp`, `bne`

## 8. Naming Conventions
To balance readability and clarity, we use a naming convention based on **Usage**:

### **`UPPER_CASE`**: Hardware & Settings
Use all-caps for fixed platform features or "set-and-forget" configuration values.
*   **Hardware Registers**: `MSTAT`, `BKGRND`, `AY_ADDR` (Fixed by the Atari/YM hardware)
*   **Build Settings**: `NTSC_HZ`, `PLAYER_HZ`, `PLAYER_ZP_BASE` (Configured in the Makefile/Source)
*   **Offsets/Math**: `TPLAYER_STATE_SIZE`, `MUSIC_STEP` (Fixed calculations)

### **`snake_case`**: Logic & Storage
Use lowercase for the "living" parts of the code—things you jump to, store data in, or read data from.
*   **RAM Variables**: `music_ptr`, `frame_cnt`, `v_frame` (Storage locations that change)
*   **Code Labels**: `main_loop`, `play_frame`, `init_music` (Entry points for instructions)
*   **Data Labels**: `music_data`, `bit_table` (Binary data in ROM)

## Summary: A Universal Template
```assembly
; ============================================================
; template.asm -- Universal 6502 Source
; ============================================================

    .if MADS
      opt h- f+
      icl "maria.inc"
      blk none $8000
    .else
      processor 6502
      include "maria.inc"
      org $8000
    .endif

reset:
    sei
    cld
    ldx #$ff
    txs

main_loop:
    ; Wait for VSync
v1: bit MSTAT
    bmi v1
v2: bit MSTAT
    bpl v2
    jmp main_loop

    ; --- Footer ---
    .if MADS
        .align $fff8, $ff
        .byte $ff, $83
        .word reset, reset, reset
    .else
        org $fff8, $ff
        .byte $ff, $83
        .word reset, reset, reset
    .endif
```

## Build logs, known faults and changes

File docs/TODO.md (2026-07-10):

# Project TODO

## Features

- [x] ~~**POKEY@$800 mapping** — implement alternative memory mapping at `$0800` (POKEY-compatible) for the YM2149.~~ *(Done: both 28-pin and 32-pin boards now decode the YM2149 at $0800/$0801 instead of $4000/$4001. See `pld/rom_ym_28pin.pld`, `pld/rom_ym_32pin.pld`, and [Hardware.md](Hardware.md#memory-mapping). Follow-up: the `a7800`/`js7800` emulator forks still hardcode $4000-range detection via the `.a78` header's bit-6 flag — see [Emulation.md](Emulation.md) — and need a corresponding update.)*

## PCB Design

Remaining issues from the PCB design review.

### High

- [ ] **Bulk decoupling capacitor** — no 10–100µF electrolytic near power entry (VCC/GND). Standard practice for cartridge designs.
- [x] ~~**Decoupling cap placement** — C1–C4 and CBYPASS are 15–20mm from their respective ICs. Move closer to VCC pins for better noise immunity.~~ *(Fixed/Invalid: Because the ICs are rotated 270°, their long axis lies along the X-axis. For example, U1 (DIP-28) extends to X=17.78mm, meaning C1 at X=20mm is physically only 2.2mm from the chip edge. All decoupling caps are within ~2mm of their respective IC pins).*

### Medium

- [ ] **Mounting holes** — cartridge PCB has no mounting holes for standoffs/screws inside the shell.
- [x] ~~**Silkscreen overlap** — `"Lokey 7800 YM v0.1"` sits at Y=-30.25mm, which is inside the edge connector region and will be obscured inside the cartridge slot.~~ *(Fixed: Moved to Y=36mm/33mm, near the top of the board).*

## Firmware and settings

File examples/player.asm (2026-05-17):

; =========================================================
; player.asm -- YM2149 MVP Player for Atari 7800 (Universal)
; =========================================================

    .if MADS
      opt h- f+
      icl "maria.inc"
      icl "ym2149.inc"
      icl "ymb.inc"
      blk none $8000
    .else
      processor 6502
      include "maria.inc"
      include "ym2149.inc"
      include "ymb.inc"
      org $8000
    .endif

PLAYER_ZP_BASE = $80

music_ptr   = PLAYER_ZP_BASE + TPLAYER_STATE_MUSIC_PTR 
frame_cnt   = PLAYER_ZP_BASE + TPLAYER_STATE_FRAME_CNT 
pat_frames  = PLAYER_ZP_BASE + TPLAYER_STATE_PAT_FRAMES 
seq_idx     = PLAYER_ZP_BASE + TPLAYER_STATE_SEQ_IDX 
tmp_mask    = PLAYER_ZP_BASE + TPLAYER_STATE_TMP_MASK 
pat_table   = PLAYER_ZP_BASE + TPLAYER_STATE_PAT_TABLE 
pat_base    = PLAYER_ZP_BASE + TPLAYER_STATE_PAT_BASE 
seq_base    = PLAYER_ZP_BASE + TPLAYER_STATE_SEQ_BASE 
pat_size    = PLAYER_ZP_BASE + TPLAYER_STATE_PAT_SIZE 
music_acc   = PLAYER_ZP_BASE + TPLAYER_STATE_MUSIC_ACC ; 2 bytes
music_delta = PLAYER_ZP_BASE + TPLAYER_STATE_MUSIC_DELTA ; 2 bytes
v_frame     = PLAYER_ZP_BASE + TPLAYER_STATE_V_FRAME ; 2 bytes

    .if MADS
        icl "music_bin.inc"
    .else
        include "music_bin.inc"
    .endif

NTSC_HZ = 60

reset:
        sei
        cld
        ldx #$ff
        txs

        ldx #$00
        ldy #$00
p_1:    dex
        bne p_1
        dey
        bne p_1

        jsr init_music
        
        ldx #NUM_REGS-1
cl_y:
        stx AY_ADDR
        lda #0
        sta AY_DATA
        dex
        bpl cl_y

main_loop:
        jsr sync_vbi
        jsr update_visuals
        
        clc
        lda music_acc
        adc music_delta
        sta music_acc
        lda music_acc+1
        adc music_delta+1
        sta music_acc+1
        bcc _skip
        jsr play_frame
_skip:
        jmp main_loop

sync_vbi:
v1:     bit MSTAT
        bmi v1
v2:     bit MSTAT
        bpl v2
        
        inc v_frame
        bne _no_hi
        inc v_frame+1
_no_hi:
        rts

update_visuals:
        lda v_frame
        lsr
        lsr
        lsr
        lsr
        lsr
        and #$07
        sta tmp_mask ; Temporary storage for first part of color calculation

        lda v_frame+1
        asl
        asl
        asl
        and #$08
        ora tmp_mask
        
        and #$0F
        asl
        asl
        asl
        asl
        ora #$08
        sta BKGRND
        rts

init_music:
        lda #0
        sta frame_cnt
        sta frame_cnt+1
        sta seq_idx
        sta pat_frames 
        sta music_acc
        sta music_acc+1
        sta v_frame
        sta v_frame+1

MUSIC_STEP = ( (PLAYER_HZ * 65536) / NTSC_HZ )

        lda #<MUSIC_STEP
        sta music_delta
        lda #>MUSIC_STEP
        sta music_delta+1

        lda music_data + TMUSIC_HEADER_PAT_SIZE
        sta pat_size

        clc
        lda #<music_data
        adc #TMUSIC_HEADER_SIZE
        sta seq_base
        lda #>music_data
        adc #0
        sta seq_base+1

        clc
        lda seq_base
        ldy #TMUSIC_HEADER_SEQ_LEN
        adc music_data,y
        sta pat_table
        lda seq_base+1
        adc #0
        sta pat_table+1

        ldy #TMUSIC_HEADER_NUM_PATTERNS
        lda music_data,y
        asl
        tay
        lda #0
        rol
        tax
        
        clc
        tya
        adc pat_table
        sta pat_base
        txa
        adc pat_table+1
        sta pat_base+1
        rts

play_frame:
        lda frame_cnt+1
        cmp #>MAX_FRAMES
        bne _check_pattern
        lda frame_cnt
        cmp #<MAX_FRAMES
        bcc _check_pattern
        
        jsr init_music

_check_pattern:
        lda pat_frames
        bne _do_play
        
        ldy seq_idx
        lda (seq_base),y
        inc seq_idx
        
        asl
        tay
        lda (pat_table),y
        sta music_ptr
        iny
        lda (pat_table),y
        sta music_ptr+1
        
        clc
        lda music_ptr
        adc pat_base
        sta music_ptr
        lda music_ptr+1
        adc pat_base+1
        sta music_ptr+1
        
        lda pat_size
        sta pat_frames

_do_play:
        dec pat_frames

        ldy #0
        lda (music_ptr),y
        sta tmp_mask
        iny
        lda (music_ptr),y
        sta tmp_mask+1
        
        clc
        lda music_ptr
        adc #2
        sta music_ptr
        lda music_ptr+1
        adc #0
        sta music_ptr+1

        ldx #0
_reg_loop_low:
        lda bit_table,x
        and tmp_mask
        beq _next_reg_low
        
        stx AY_ADDR
        ldy #0
        lda (music_ptr),y
        sta AY_DATA
        
        inc music_ptr
        bne _next_reg_low
        inc music_ptr+1

_next_reg_low:
        inx
        cpx #8
        bne _reg_loop_low

_reg_loop_high:
        txa
        and #$07
        tay
        lda bit_table,y
        and tmp_mask+1
        beq _next_reg_high

        stx AY_ADDR
        ldy #0
        lda (music_ptr),y
        sta AY_DATA
        
        inc music_ptr
        bne _next_reg_high
        inc music_ptr+1

_next_reg_high:
        inx
        cpx #NUM_REGS
        bne _reg_loop_high

        inc frame_cnt
        bne _p_done
        inc frame_cnt+1
_p_done:
        rts

bit_table:
        .byte $01, $02, $04, $08, $10, $20, $40, $80

    .if MADS
        .align $fff8, $ff
        .byte $ff, $83
        .word reset, reset, reset
    .else
        org $fff8, $ff
        .byte $ff, $83
        .word reset
        .word reset
        .word reset
    .endif

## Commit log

2026-03-08 fixed vbi sample, remove unused samples
2026-03-20 Update build system, replace GAL logic, and add YM music samples.
2026-03-29 start of potential pcb in Python
2026-03-29 update PCB, build, and readme
    [7800-ym.kicad_pcb]
2026-03-29 update background on schematic SVG
2026-03-29 update readme and schematic svg
2026-04-01 intial trial of tscircuit
    [7800-ym.kicad_pcb]
2026-04-01 use kicad 9
2026-04-02 rearrange pcb
2026-04-02 adjust pcb layout
2026-04-02 add edge connector notch
2026-04-06 update circuit
2026-04-08 switch to galette, update readme
2026-04-14 add note about assembler used
2026-04-17 add schematic PDF
2026-05-10 sync up with prototype
2026-05-16 bug fix in PCB and sample-code
2026-05-16 added experimental ca65 build
    [7800.cfg]
2026-05-16 experiment begin with MAD assembler
2026-05-17 remove ca65/mads sub projects
    [7800.cfg]
2026-06-03 cleanup schematic
2026-06-04 rework PCB
2026-06-05 add clearer nodes about op-amp and YM power on reset
2026-06-07 update PCB
2026-06-07 update schematic
2026-06-08 update PCB, add exported KiCad project
    [index.dsn, index.kicad_pcb, index.kicad_sch]
2026-06-11 update schematics and KiCad
    [index.kicad_pcb]
2026-06-11 remove unused files
    [index.dsn, index.kicad_sch]
2026-06-15 update PCB build process
    [index-B_Courtyard.gbr, index-B_Cu.gbl, index-B_Fab.gbr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]
2026-06-15 move patch for pcb to pcb subproject
2026-06-15 update gerbers
    [index-B_Courtyard.gbr, index-B_Cu.gbl, index-B_Fab.gbr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]
2026-06-15 small update to PCB and add TODO.md
    [index-B_Courtyard.gbr, index-B_Cu.gbl, index-B_Fab.gbr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]
2026-06-16 cleanup pcb build
    [index-B_Courtyard.gbr, index-B_Cu.gbl, index-B_Fab.gbr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]
2026-06-16 add previews and schematic to Makefile
2026-06-16 fix opamp setting to match prototype
    [index-B_Courtyard.gbr, index-B_Cu.gbl, index-B_Fab.gbr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]
2026-06-16 cleanup and optimize pcb build, setup for macOS
    [index-B_Courtyard.gbr, index-B_Cu.gbl, index-B_Fab.gbr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]
2026-06-17 reorg pcb, add clean
    [index-B_Courtyard.gbr, index-B_Cu.gbl, index-B_Fab.gbr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]
2026-06-17 add PCB warning
2026-06-18 start of expansion to 16k and 64k 28 pin ROMs
    [index-B_Courtyard.gbr, index-B_Cu.gbl, index-B_Fab.gbr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]
2026-06-18 update make pcb path
    [index-B_Courtyard.gbr, index-B_Cu.gbl, index-B_Fab.gbr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]
2026-06-19 update PCB, move text
    [index-B_Courtyard.gbr, index-B_Cu.gbl, index-B_Fab.gbr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]
2026-06-23 update cart outline to fit cartridge case, update documents to outline where we are taking this
2026-06-24 attempt new layout
    [index-B_Courtyard.gbr, index-B_Cu.gbl, index-B_Fab.gbr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]
2026-06-26 start of support for 32-pin ROM
2026-06-27 update PCB and hardware doc
2026-06-28 update PCB for 28pin 16k, 32k, 64k rom
    [index-B_Courtyard.gbr, index-B_Cu.gbl, index-B_Fab.gbr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]
2026-06-28 use consistent values for pcb x and y
2026-06-29 reorg project, add GitHub workflows
    [index-B_Courtyard.gbr, index-B_Cu.gbl, index-B_Fab.gbr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]
2026-07-02 fix capacitor placement
2026-07-02 update capacitor and resistor spacing
2026-07-05 update routing and resistor size, update Python script
    [index-B_Courtyard.gbr, index-B_Cu.gbl, index-B_Fab.gbr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]
2026-07-06 add 32-pin pcb, update release
2026-07-07 update 28 pin pcb
2026-07-08 update 28pin PCB
2026-07-08 update PCBs
2026-07-09 update PCBs and GitHub release.yml
2026-07-10 update 32pin PCB and release GH actions
2026-07-11 remove everything but kitchen sink PCB
2026-07-12 minor updates to PCB layout
2026-07-12 minor PCB update
2026-07-12 update 32 pin pcb
2026-07-12 update 32-pin PCB
2026-07-12 commit dev container option for PCB build
2026-07-13 add bank selection demo, it works on emulator so it should work on real device 🙄
